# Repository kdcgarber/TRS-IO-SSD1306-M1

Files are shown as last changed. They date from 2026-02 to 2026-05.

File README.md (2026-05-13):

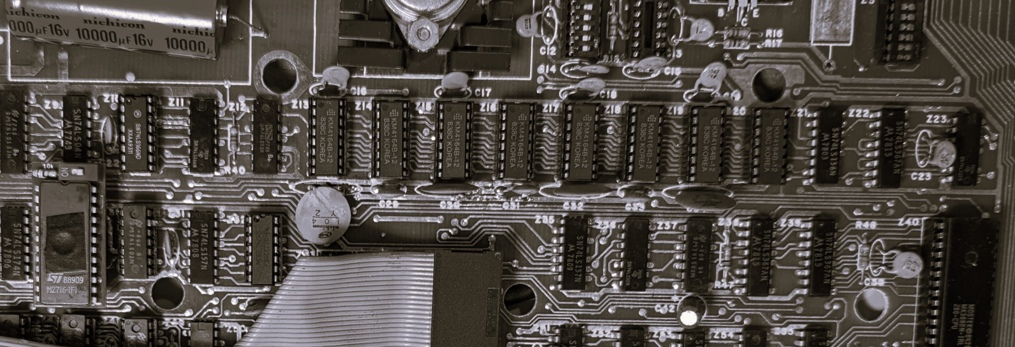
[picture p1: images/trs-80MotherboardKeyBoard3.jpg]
TRS-IO-SSD1306-M1 Header


# TRS-IO with a SSD1306 LCD display for my Model 1
<br>

These are my notes for the build of this version of my TRS-IO<br>
This repo is, like my other repo, based on a snapshot of https://github.com/apuder/TRS-IO commit f2acde6.<br>
That original repo is an amazing piece of hardware/software that provides new feature to my retro TRS-80 model 1<br>
Thanks for making that project hardware design and code avialable for others like me to use on our retro machines.

I’ve built several TRS-IO boards (the earlier versions are on my other GitHub repo), and I’ve now rebuilt them using this updated design.<br>

One challenge I ran into was keeping track of the IP address for each my TRS-IO's.<br>
So, when multiple TRS-IO units are powered on at the same time, it becomes difficult to know which device you’re actually connected to.<br>

To solve that —and mostly just for fun and to learn more— I extended the original design to include a small status display.<br>
This makes it easy to see the assigned IP address and other useful information directly from the TRS-IO itself.<br>

Because this codebase has diverged from the original TRS-IO backported source, I can no longer pull an upstream updates if there are any.<br>
If the original repository is updated in the future, those changes won’t be reflected here unless manually merged.<br>
That said, most current development in this space appears to be shifting toward TRS-IO++, so upstream changes may be minimal going forward.<br>

These notes document the steps I took to configure this new hardware design with my modified software.<br>
They are just notes. They’re primarily for my own reference, but they may also be helpful to others following a similar path.<br>

The new, smaller PCB files that include the display are available in this repo.<br>

The only real difference for the hardware of my board is the part layout <br>
and removing the LED and its resistors to be replaced with a SSD1306 display. <br>
Any TRS-IO could be changed to replace the LED, it just has no mount to hold the display in place, though one can be created. <br>

<table>
  <tr>
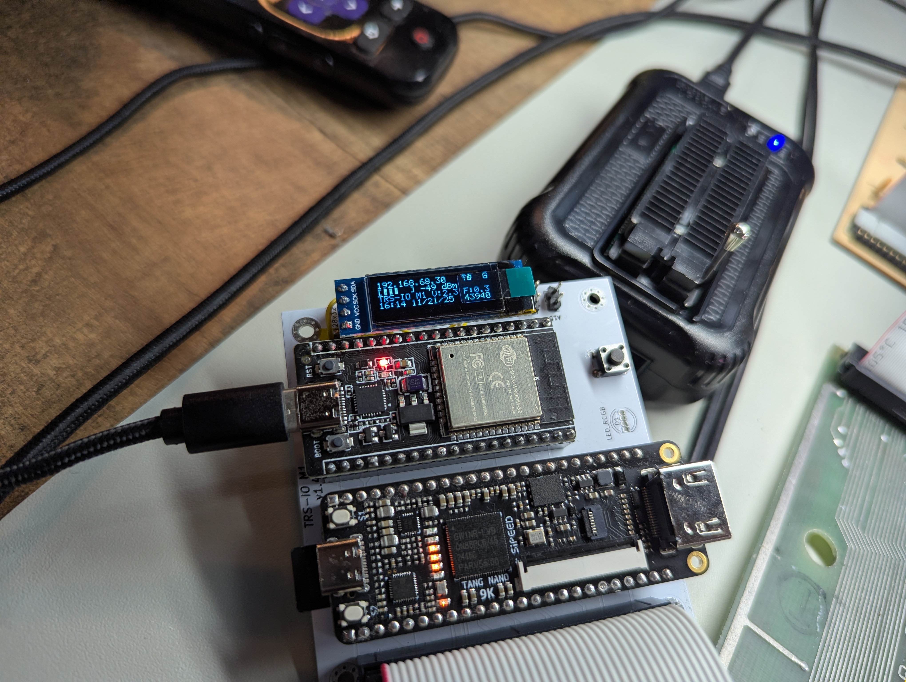
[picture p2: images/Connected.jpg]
	<td></td>
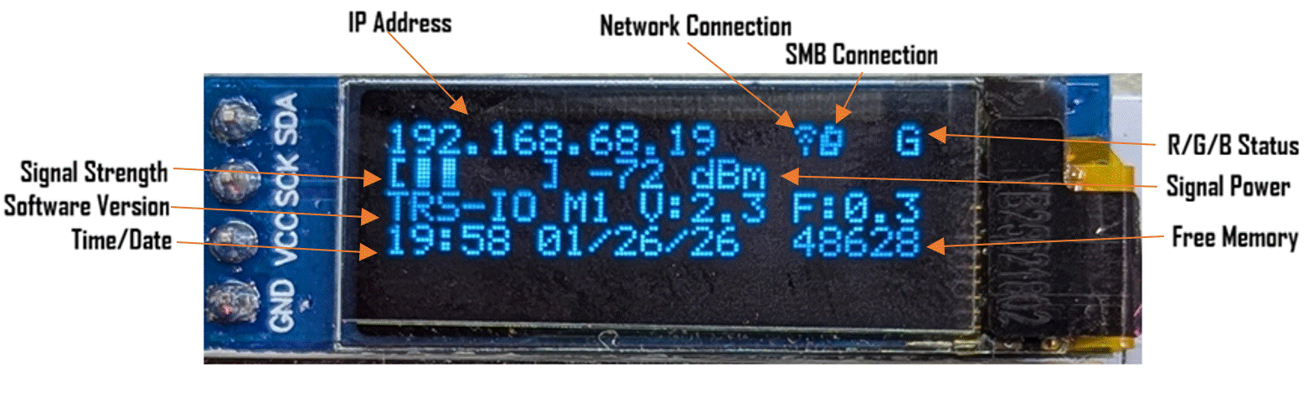
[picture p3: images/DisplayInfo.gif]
	<td></td>
  </tr>
</table>

<bre>

## 📂 Content in repository

	.
	├── DebugNotes.txt                       - Notes to setup my PC to view output from the ESP-WROOM-32 usb port
	├── SDcardM1auto.zip                     - SD card files for the SMB share
	├── 3d                                   - STL files to 3D print a case for the new TRS-IO-SSD1306
	├── buildFiles                           - FPGA file
	├── doc                                  - Doc from the original site
	├── examples                             - Code samples form the Orignal Site
	├── images                               - Images for the github pages
	├── kicad-SSD1306                        - Contains the kicad data for the project PCB
	├── src                                  - This is the altered code for the ESP-WROOM-32
	└── src/esp/ESP-WROOOM-32-Deployment     - Compiled Binary ESP files ready for deployment

<br>

## The hardware build and BOM

All of the files for the PCB are in the kicad-SSD1306 directory.<br>
I sent the files to PCBWay to have them created.<br>
Since you pay per square millimeter of board, by placing all the surface mount components on the back sidek, I saved money on the board cost.<br>
In my final builds I opted to mount the FPGA, ESP32, and display directly to the board to decrease the thickness of the board.<br>
I've done both ways, but in the end, since these are dedicated to this, I went with directly soldering them with no sockets.<br>

<table>
  <tr>
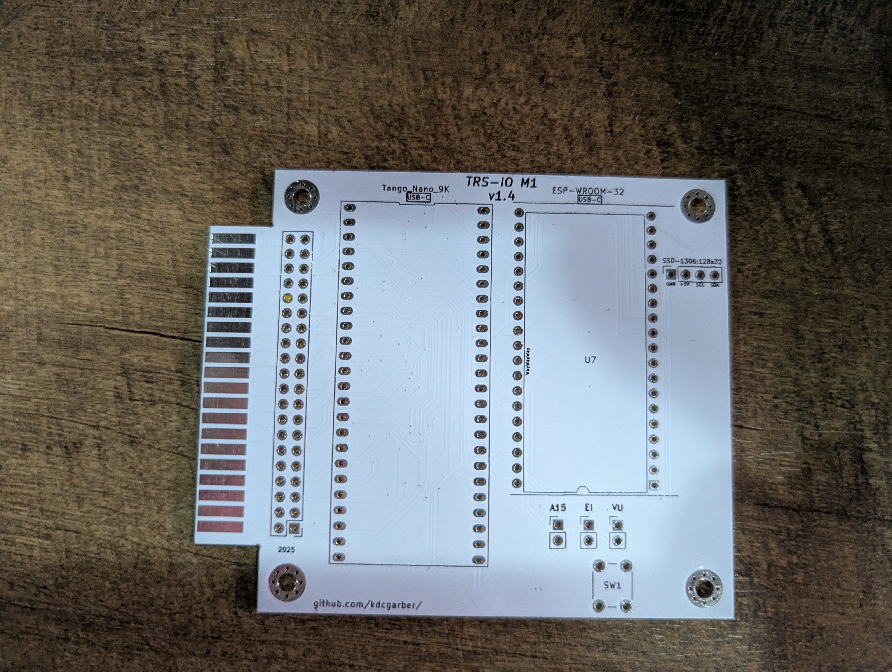
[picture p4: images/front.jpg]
    <td></td>
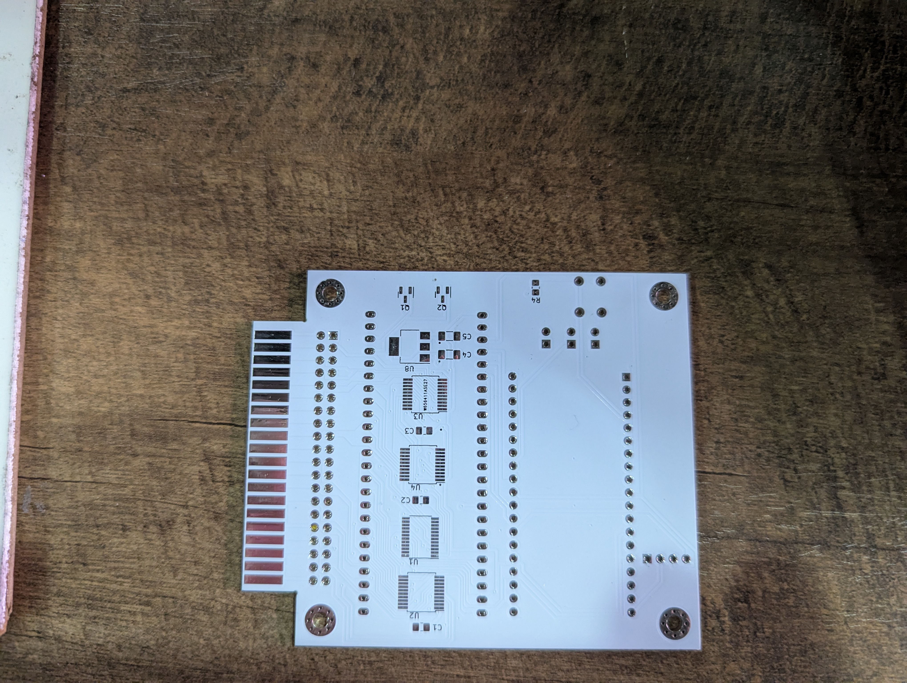
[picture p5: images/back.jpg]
    <td></td>
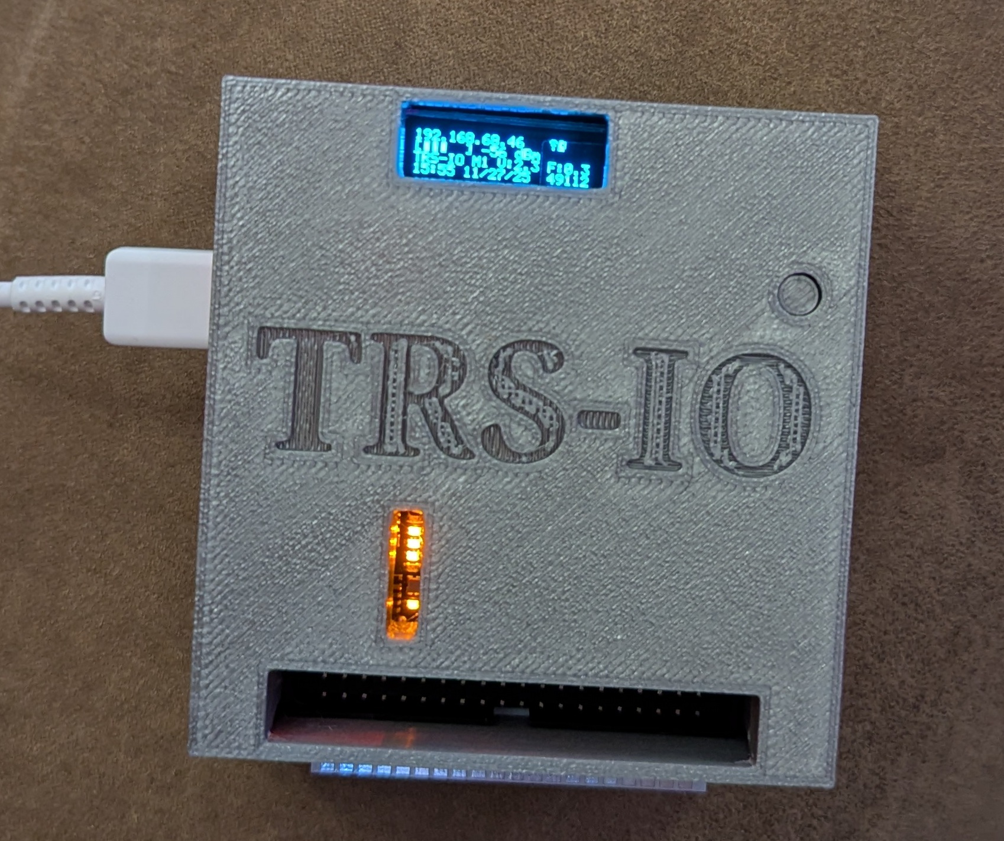
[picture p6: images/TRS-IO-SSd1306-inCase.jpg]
    <td></td>
  </tr>
  <tr>
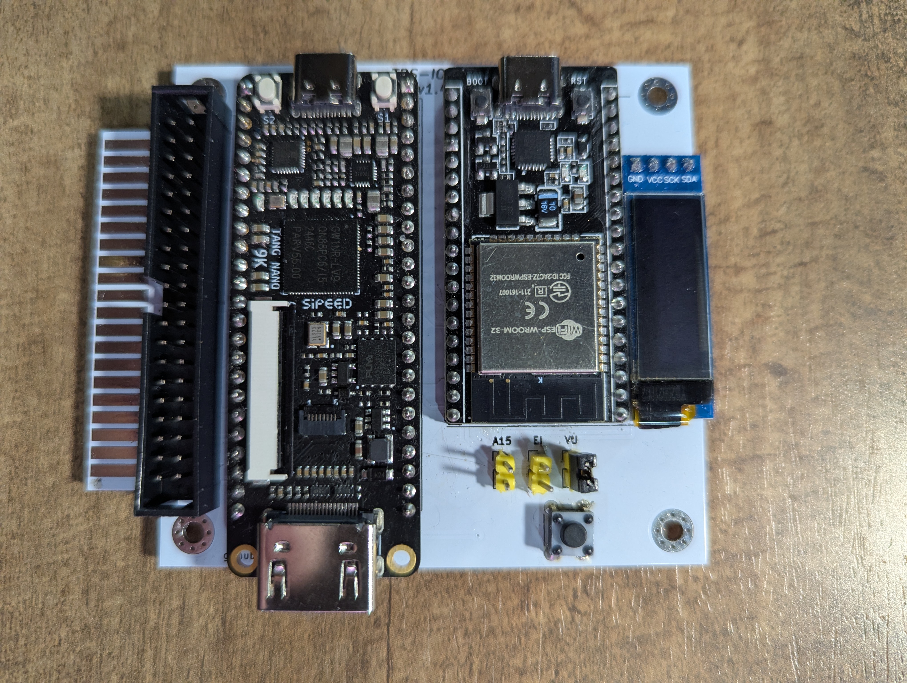
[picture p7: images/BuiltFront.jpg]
    <td></td>
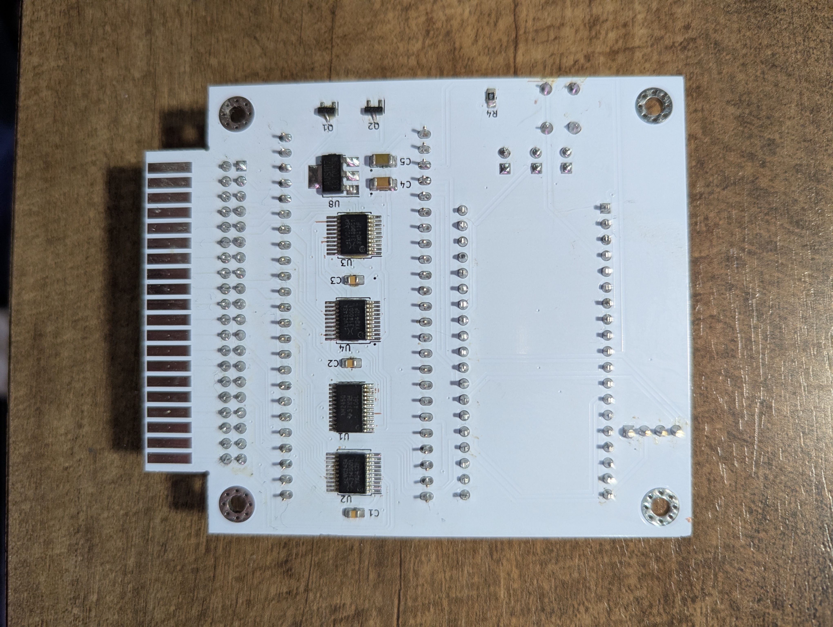
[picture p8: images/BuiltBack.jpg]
    <td></td>
  </tr>
</table>

<br>
The BOM shows the parts needed and their layout and placement.<br>

<a href="https://kdcgarber.github.io/githubPages-htmlfiles/TRS-IO-SSD1306%20bom/ibom.html" target="_blank">Parts list.</a>
<br>

## There are two paths to get the code deployed to your ESP-WROOM-32.

1 Build the files from source and deploy.<br>
2 Just use the pre-built files to flash your ESP.<br>

<br>
<br>

## Option 1 - The Software build for the ESP-WROOM-32

These notes for the code build are based on the original notes of my TRS-IO build.<br>
The code in this repo already has my code changes in it, so no to alter any code by hand.<br>
I built this for my enjoyment and to learn and have fun.<br>
These changes may not be the best code they could be, but if anyone wants to use it, they can.<br>

I used the ESP-WROOM-32 esp controller (no PSRAM) - https://www.amazon.com/dp/B0B764963C<br>
And I used the Tang Nano 9K FPGA - https://www.aliexpress.us/item/3256804089255675.html<br>

I did this code build on Ubuntu 24.04, as a non-root account<br>

### Prep - installing required components<br>
&nbsp;&nbsp;&nbsp;&nbsp;sudo apt upgrade<br>
### Packages for Espressif<br>
&nbsp;&nbsp;&nbsp;&nbsp;sudo apt-get install git wget flex bison gperf python3 python3-pip python3-setuptools cmake ninja-build ccache libffi-dev libssl-dev dfu-util libusb-1.0-0 python3-virtualenv<br>
###  Packages for TRS-IO<br>
&nbsp;&nbsp;&nbsp;&nbsp;sudo apt-get install z80asm sdcc sdcc-libraries<br>
###  Some fixes for linking libraries that are needed by TRS-IO<br>
&nbsp;&nbsp;&nbsp;&nbsp;sudo mkdir -p /lib/z80/<br>
&nbsp;&nbsp;&nbsp;&nbsp;sudo ln -s /usr/share/sdcc/lib/z80/z80.lib /lib/z80/z80.lib<br>
###  Python3 as default:<br>
&nbsp;&nbsp;&nbsp;&nbsp;sudo apt-get install python3 python3-pip python3-setuptools<br>
&nbsp;&nbsp;&nbsp;&nbsp;sudo ln -s /usr/bin/python3 /usr/bin/python<br>
<br>

###  Install ESP-IDF<br>
cd ~/<br>
mkdir esp<br>
cd esp<br>
git clone -b v4.4.7 --recurse-submodules https://github.com/espressif/esp-idf.git<br>
cd ~/esp/esp-idf<br>
./install.sh esp32<br>

### clone this repo
cd ~/esp<br>
git clone --recurse-submodules https://github.com/kdcgarber/TRS-IO-SSD1306-M1.git<br>

### TRS-IO stuff<br>
.  ~/esp/esp-idf/export.sh<br>

## Compile and Flash the ESP<br>
cd ~/esp/TRS-IO-SSD1306-M1/src/esp<br>
idf.py fullclean<br>
make BOARD=trs-io-m1-v14 build<br>

The build will show many warnings, but if it completes with no errors, the rest should be good.<br>
At the bottom of its output, it lists the command to run. The port needs to be changed to match the correct port.<br>

Sometimes while doing the flash, it fails. If it does, just try it again and it will load.<br><br>
~/esp/esp-idf/components/esptool_py/esptool/esptool.py -p /dev/ttyUSB0  -b 460800 --before default_reset --after hard_reset --chip esp32  write_flash --flash_mode dio --flash_size detect --flash_freq 40m 0x1000 build/bootloader/bootloader.bin 0x8000 build/partition_table/partition-table.bin 0x10000 build/trs-io.bin 0x190000 build/html.bin<br>

<br><br><br>

## 💾 Option 2 - Just use the pre-built bin files
<br>
This path is to flash the ESP-WROOM-32 from the provided files without a full code rebuild. <br>
The code does not need to be recompiled unless you are making changes or just want to.
This directory contains 4 files that are the files needed for the ESP: src/esp/ESP-WROOOM-32-Deployment<br>
<br>
• bootloader.bin<br>
• html.bin<br>
• partition-table.bin<br>
• trs-io.bin<br>
<br>

To use these files you'll need to to install ESPTOOL and then deploy the code.<br>
I did my file flash from the files via a windows 11 PC.<br>

From a windows command shell (CMD)<br>
### Check that Python and PIP are installed and install if they are not found. 
python --version<br>
&nbsp;&nbsp;Python 3.12.10<br>

pip --version <br>
&nbsp;&nbsp;pip 25.3 from C:\Users\toddr\AppData\Local\Packages\PythonSoftwareFoundation.Python.3.12_qbz5n2kfra8p0\LocalCache\local-packages\Python312\site-packages\pip (python 3.12)<br>

### This installs the ESPTOOL
pip install esptool<br>

### Add a shortcut to get to the path to use the ESPTOOL
doskey esptool="C:\Users\toddr\AppData\Local\Packages\PythonSoftwareFoundation.Python.3.12_qbz5n2kfra8p0\LocalCache\local-packages\Python312\Scripts\esptool.exe" $* <br>

ESPTOOL should now work<br>

Just enter "esptool", it should give the default help windows message<br>
Plug your ESP-WROOM-32 in via the usb port to your windows 11 pc.<br>

### Now to find the COM port
With the esp plugged into the laptop in windows 11, "mode" will show the COM it's connected to.<br>
The COM will need to be used on the flash command<br>

mode<br>

Status for device COM5:<br>
Baud:            115200<br>
Parity:          None<br>
Data Bits:       8<br>
Stop Bits:       1<br>
Timeout:         OFF<br>
XON/XOFF:        OFF<br>
CTS handshaking: OFF<br>
DSR handshaking: OFF<br>
DSR sensitivity: OFF<br>
DTR circuit:     OFF<br>
RTS circuit:     OFF<br>
<br>

### Move to your code repo and move to the src/esp/ directory. <br>
cd "C:\Users\toddr\OneDrive\Shared\Todd\GitHub\trsnic-ssd1306\src\esp"<br>

There will be 4 bin files in the directory ESP-WROOOM-32-Deployment which will be flashed to the ESP. <br>
 ### Run this command
(Replace COM5 with your actual COM port number if necessary.) <br>

esptool --chip esp32 --port COM5 --baud 460800 write-flash --flash-mode dio --flash-size detect --flash-freq 40m -z 0x1000 ESP-WROOOM-32-Deployment\bootloader.bin 0x8000 ESP-WROOOM-32-Deployment\partition-table.bin 0x10000 ESP-WROOOM-32-Deployment\trs-io.bin 0x190000 ESP-WROOOM-32-Deployment\html.bin <br>

This should flash the ESP and it will now be ready to use.<br>

# Flash the FPGA

### Install openFPGALoader

apt install \\<br>
  git \\<br>
  gzip \\<br>
  libftdi1-2 \\<br>
  libftdi1-dev \\<br>
  libhidapi-hidraw0 \\<br>
  libhidapi-dev \\<br>
  libudev-dev \\<br>
  zlib1g-dev \\<br>
  cmake \\<br>
  pkg-config \\<br>
  make \\<br>
  g++

git clone https://github.com/trabucayre/openFPGALoader<br>
cd openFPGALoader<br>
mkdir build<br>
cd build<br>
cmake .. <br>
cmake --build .<br>
make install<br>

### The FPGA file is TRS-IO.fs<br>

cd  ~/esp/buildFiles<br>
openFPGALoader -b tangnano9k -f TRS-IO.fs

	EXAMPLE:
	root@thebox:/home/kdcgarber/esp/buildFiles# openFPGALoader -b tangnano9k -f TRS-IO.fs

	empty
	write to flash
	Jtag frequency : requested 6.00MHz   -> real 6.00MHz
	Parse file Parse TRS-IO.fs:
	Done
	DONE
	Jtag frequency : requested 2.50MHz   -> real 2.00MHz
	Erase SRAM DONE
	Erase FLASH DONE
	Erasing FLASH: [==================================================] 100.00%
	Done
	write Flash: [==================================================] 100.00%
	Done
	CRC check: Success

<br>

* There is also a newer version of the TRS-IO.fs that I now use. It provides higher resolution glyphs that can be used instead of the original TRS-IO.fs file. It is called TRS-IO-v1_4-HiRes.fs and can be flashed to replace the TRS-IO.fs I used originally.  
openFPGALoader -b tangnano9k -f TRS-IO-v1_4-HiRes.fs

## All done with the Install

After the install is complete, follow the notes on the TRS-IO site to bring up the trs-io.local access point<br> 
and start the configuration.<br>
The site also has the ROM boot loader for the FreHD to go on the SD card<br>
or the SMB (windows share or for me SAMBA share on my Linux server).<br>

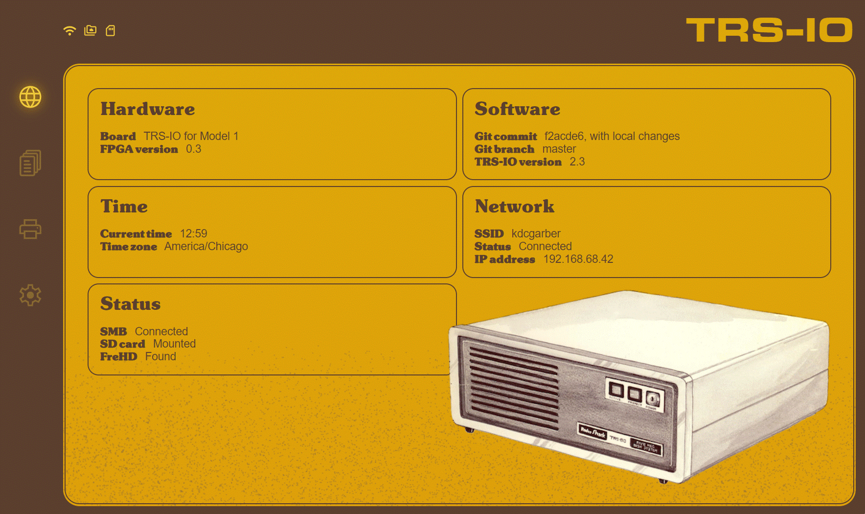
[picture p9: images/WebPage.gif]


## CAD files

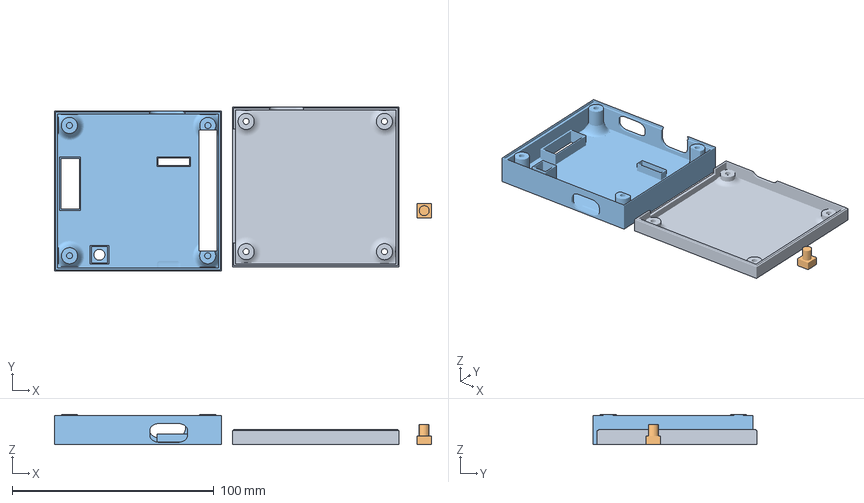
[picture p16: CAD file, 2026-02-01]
kicad-SSD1306/TRS-IO-M1-v1.4-TRG-SSD1306-v6/Case/TRS-IO-M1-v1.4-TRG-SSD1306-v6-FullCase.3mf
186.8 x 81.4 x 15.0 mm
TRS-IO-M1-v1.4-TRG-SSD1306-v6-bottom.stl
TRS-IO-M1-v1.4-TRG-SSD1306-v6-button.stl
TRS-IO-M1-v1.4-TRG-SSD1306-v6-Top.stl

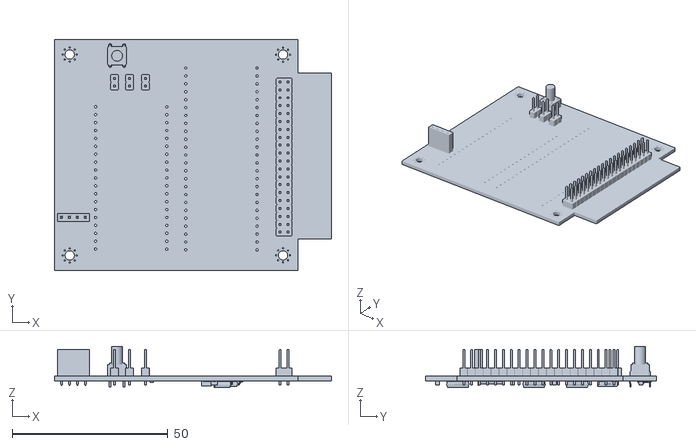
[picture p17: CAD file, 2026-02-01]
3d/TRS-IO Case SSD1306-boardforfun.stl
89.0 x 74.2 x 13.3

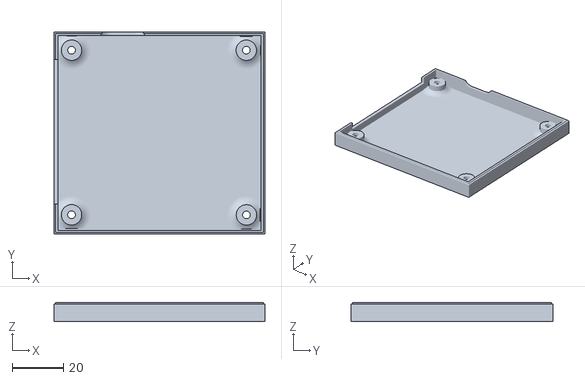
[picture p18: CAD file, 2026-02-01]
kicad-SSD1306/TRS-IO-M1-v1.4-TRG-SSD1306-v6/Case/TRS-IO-M1-v1.4-TRG-SSD1306-v6-bottom.stl
82.7 x 79.3 x 7.50

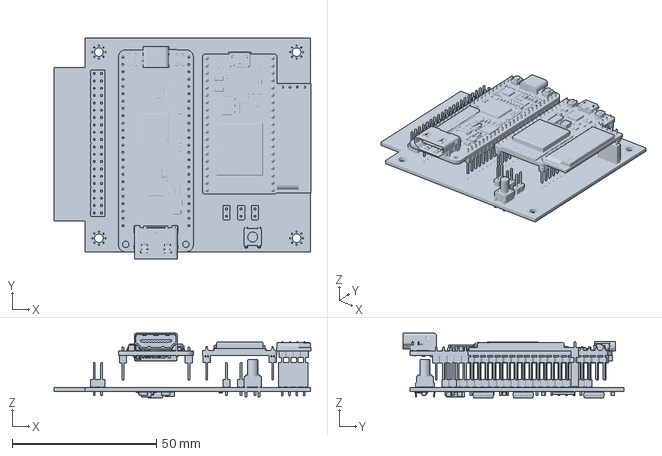
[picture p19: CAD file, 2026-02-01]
kicad-SSD1306/TRS-IO-M1-v1.4-TRG-SSD1306-v6/TRS-IO-M1-v1.4-TRG-SSD1306-v6.3mf
89.1 x 76.5 x 22.5 mm

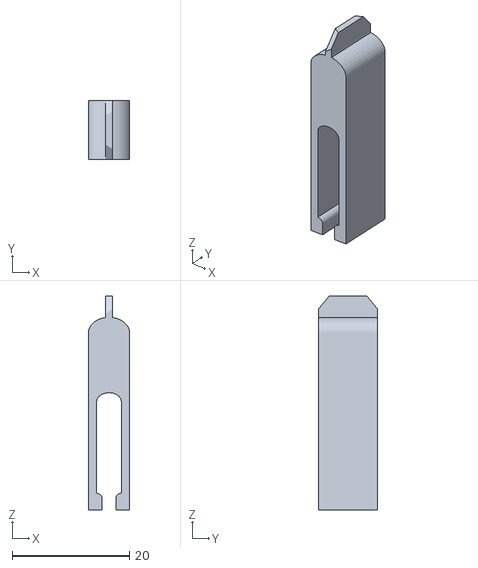
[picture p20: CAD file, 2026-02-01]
3d/Micro_SD_Card_Tool.stl
7.00 x 10.00 x 36.5

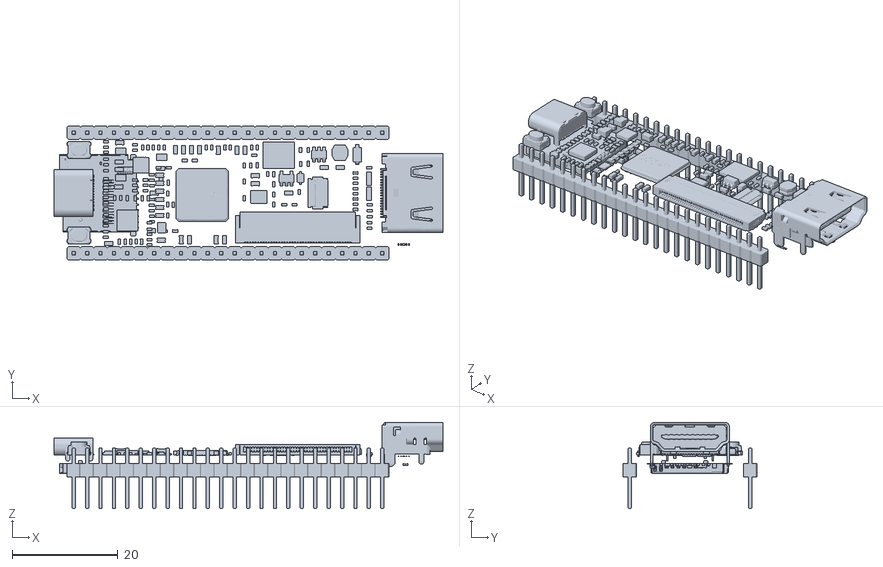
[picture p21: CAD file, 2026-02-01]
kicad-SSD1306/TRS-IO-M1-v1.4-TRG-SSD1306-v6/Tang_Nano_9K_3672.stl
73.6 x 25.4 x 16.4

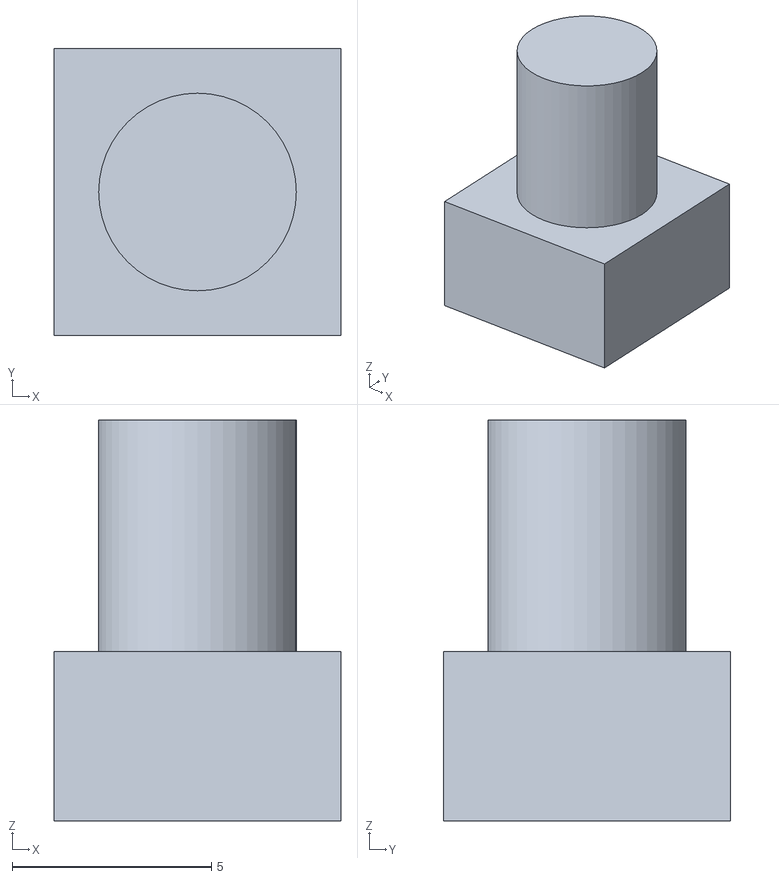
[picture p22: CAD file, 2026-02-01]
3d/TRS-IO Case SSD1306-button.stl
7.20 x 7.20 x 10.1

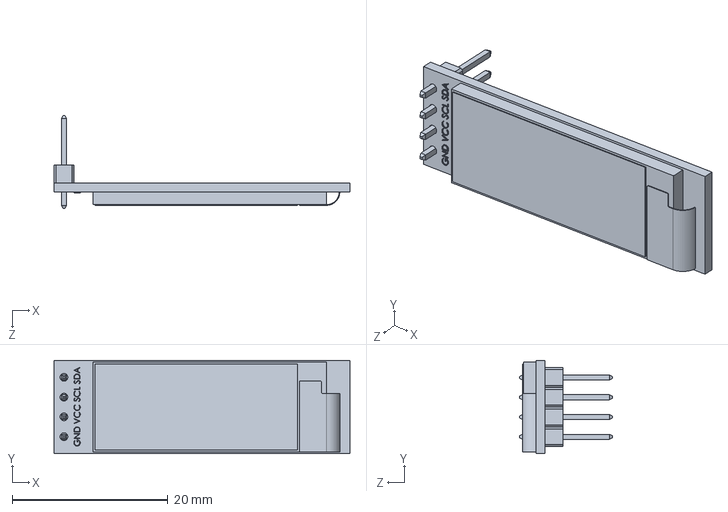
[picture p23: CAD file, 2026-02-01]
kicad-SSD1306/TRS-IO-M1-v1.4-TRG-SSD1306-v6/128x32-OLED.STEP
38.0 x 12.0 x 11.9 mm

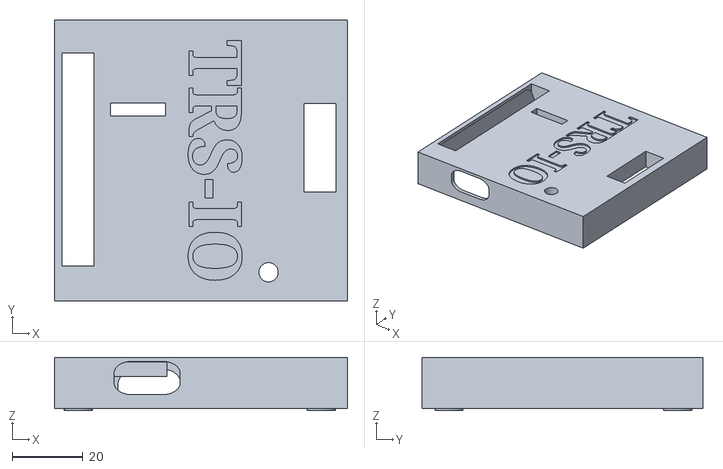
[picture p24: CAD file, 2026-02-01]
kicad-SSD1306/TRS-IO-M1-v1.4-TRG-SSD1306-v6/Case/TRS-IO-M1-v1.4-TRG-SSD1306-v6-Top.stl
82.7 x 79.3 x 15.0

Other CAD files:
kicad-SSD1306/TRS-IO-M1-v1.4-TRG-SSD1306-v6/Case/TRS-IO-M1-v1.4-TRG-SSD1306-v6-button.stl
3d/TRS-IO Case SSD1306-Bottom.stl
kicad-SSD1306/TRS-IO-M1-v1.4-TRG-SSD1306-v6/TRS-IO-M1-v1.4-TRG-SSD1306-v6-ReducefileSize-1.stl
3d/TRS-IO Case SSD1306-Top.stl
kicad-SSD1306/TRS-IO-M1-v1.4-TRG-SSD1306-v6/TRS-IO-M1-v1.4-TRG-SSD1306-v6.stl

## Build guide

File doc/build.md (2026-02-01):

#### TRS-IO - Circuit Board Bill of Materials

|Qty|Ref|Digikey Part#|Manuf Part #|Description|
|:---|:---|:---|:---|:---|
|1|U1||ESP32 MODULE|Refer to Supported ESP32 Modules
|1|U3|[ATF16V8B-15PU-ND](https://www.digikey.com/product-detail/en/microchip-technology/ATF16V8B-15PU/ATF16V8B-15PU-ND/1118926)|ATF16V8B-15PU|IC PLD 8MC 15NS 20DIP
|2|U2,U4|[296-8503-5-ND](https://www.digikey.com/product-detail/en/texas-instruments/SN74LVC245AN/296-8503-5-ND/377483)|SN74LVC245AN|IC TXRX NON-INVERT 3.6V 20DIP
|3|Q1,Q2,Q3|[2N7000-G-ND](https://www.digikey.com/product-detail/en/microchip-technology/2N7000-G/2N7000-G-ND/4902350)|2N7000-G|MOSFET N-CH 60V 0.2A TO92-3
|1|D1|[1830-1014-ND](https://www.digikey.com/product-detail/en/inolux/HV-5RGB60/1830-1014-ND/7604616)|HV-5RGB60|LED RGB DIFFUSED 5MM T/H
|1|SW1|[450-1650-ND](https://www.digikey.com/product-detail/en/te-connectivity-alcoswitch-switches/1825910-6/450-1650-ND/1632536)|1825910-6|SWITCH TACTILE SPST-NO 0.05A 24V
|1|SW2||1825910-6|SWITCH TACTILE RIGHT-ANGLE SPST-NO 0.05A 24V
|3|U2,U3,U4|[ED3054-5-ND](https://www.digikey.com/product-detail/en/on-shore-technology-inc/ED20DT/ED3054-5-ND/4147598)|ED20DT|CONN IC DIP SOCKET 20POS TIN
|1|J1|[ED10530-ND](https://www.digikey.com/product-detail/en/on-shore-technology-inc/302-S501/ED10530-ND/2794241)|302-S501|CONN HEADER VERT 50POS 2.54MM
|1||[HDR100IMP40F-G-V-TH-ND](https://www.digikey.com/product-detail/en/chip-quik-inc/HDR100IMP40F-G-V-TH/HDR100IMP40F-G-V-TH-ND/5978200)|HDR100IMP40F-G-V-TH|SIL HDR 40POS 0.1 GOLD PCB
|4|C1,C2,C3,C4|[490-8809-ND](https://www.digikey.com/short/pvj15w)|RDER71E104K0P1H03B|CAP CER 0.1UF 25V X7R RADIAL
|3|R1,R2,R3|||100R 0.25W
|1|R4|||4K7 0.25W

#### Supported ESP32 Modules:
The TRS-IO board supports two commonly available ESP32 modules.

* 38 Pin Module commonly branded as NodeMCU or HiLetGo

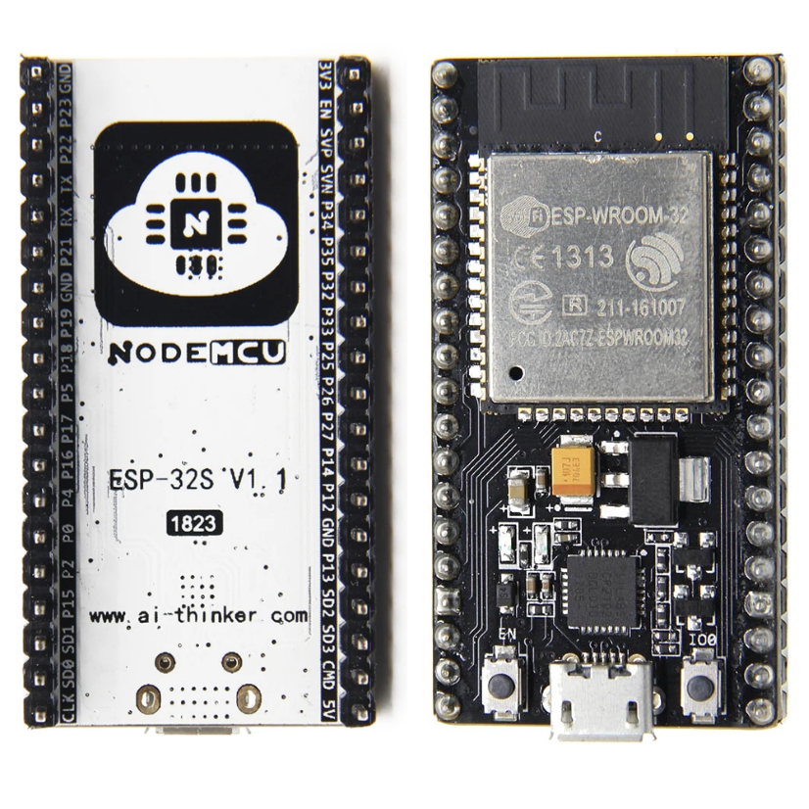
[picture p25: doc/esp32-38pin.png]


* 30 Pin Module commonly branded as DEVKITV1

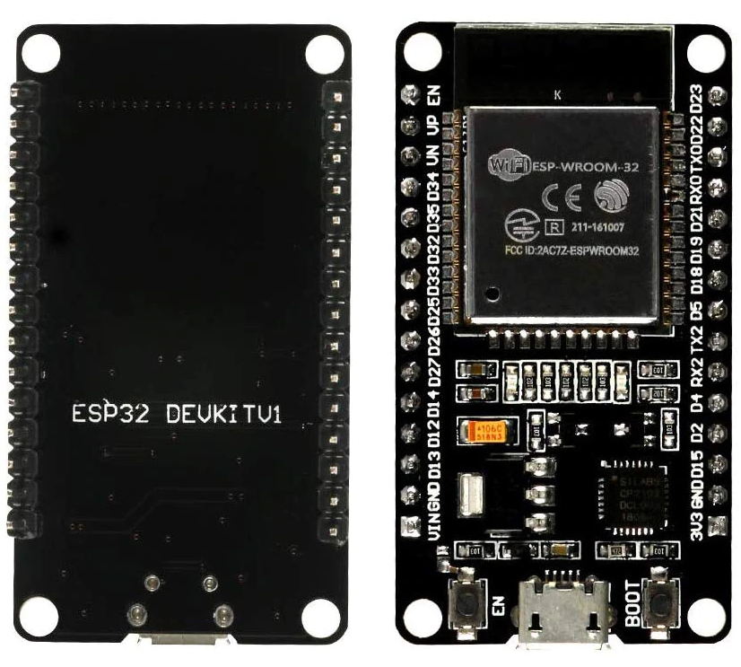
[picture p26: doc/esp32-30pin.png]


The pinout and spacing of the two modules differs.  Unless you plan to test your board with both modules, install 15 pin SIL sockets in 1st and 3rd positons for the 30 Pin Module or 19 pin SIL sockets in the 2nd and 4th positions for the 38 Pin Module.

Correct orientation of the modules is shown below:

* 38 Pin Module commonly branded as NodeMCU or HiLetGo

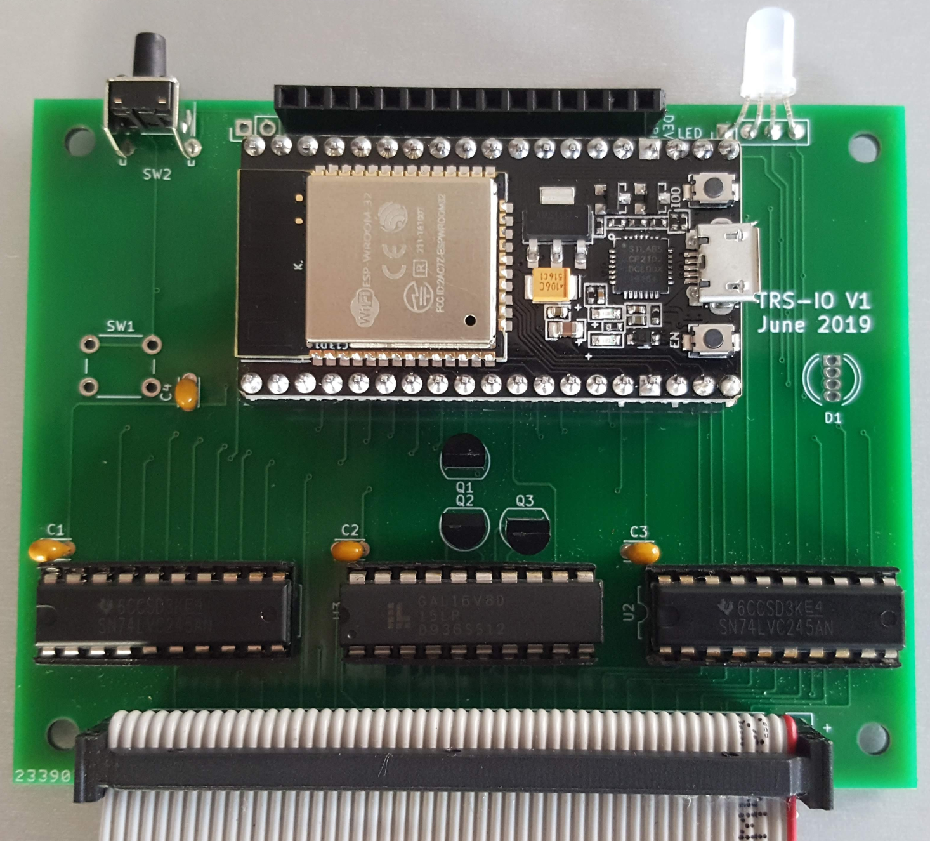
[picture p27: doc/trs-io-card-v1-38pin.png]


* 30 Pin Module commonly branded as DEVKITV1

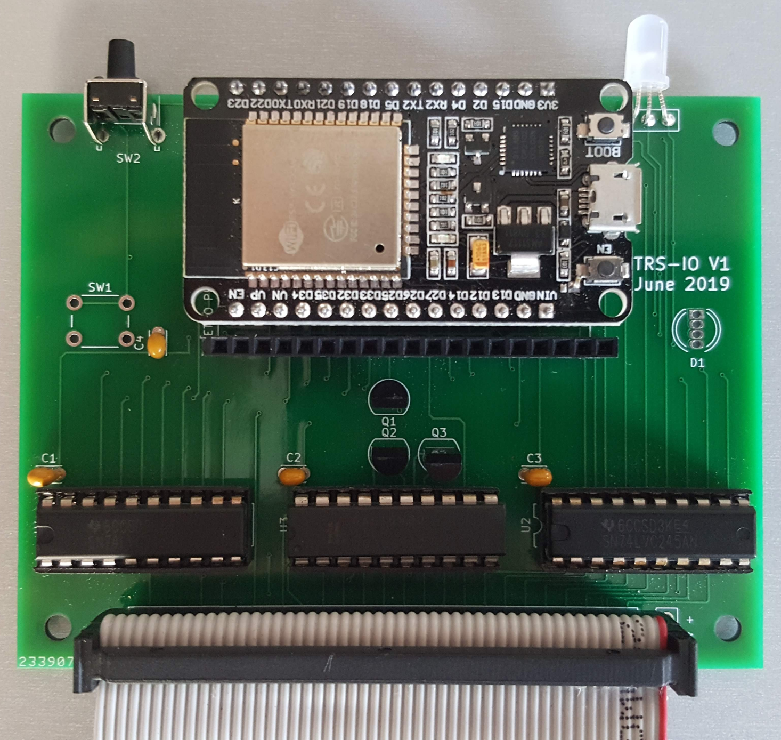
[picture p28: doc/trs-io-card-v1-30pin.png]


#### Notes:
* The switch can be installed in either SW1 or SW2.  SW2 is recommended when assembling the board for installation in a case.
* The LED can be installed in either D1 or J4.  J4 is recommended when assembling the board for installation in a case.  Do not install an LED in both D1 and J4.
* R1,R2 and R3 are current limiting resistors for the LED.  The values are not critical and may require adjustment for some LED.
* The J5 header can be installed and jumpered to disable the internal FreHD emulation when an external FreHD is connected to the expansion connector.  J5 can be omitted if an external FreHD is not used.
* R4 is a pullup for the ESP32 FreHD Inhibit signal. This must always be installed even J5 is not.  Value is not critical.  Anything between 4K7 and 10K will work.
* 5V can be connected to J5 as an alternative to powering ESP32 from USB.  This is recommended when assembling the board for installation in a case.

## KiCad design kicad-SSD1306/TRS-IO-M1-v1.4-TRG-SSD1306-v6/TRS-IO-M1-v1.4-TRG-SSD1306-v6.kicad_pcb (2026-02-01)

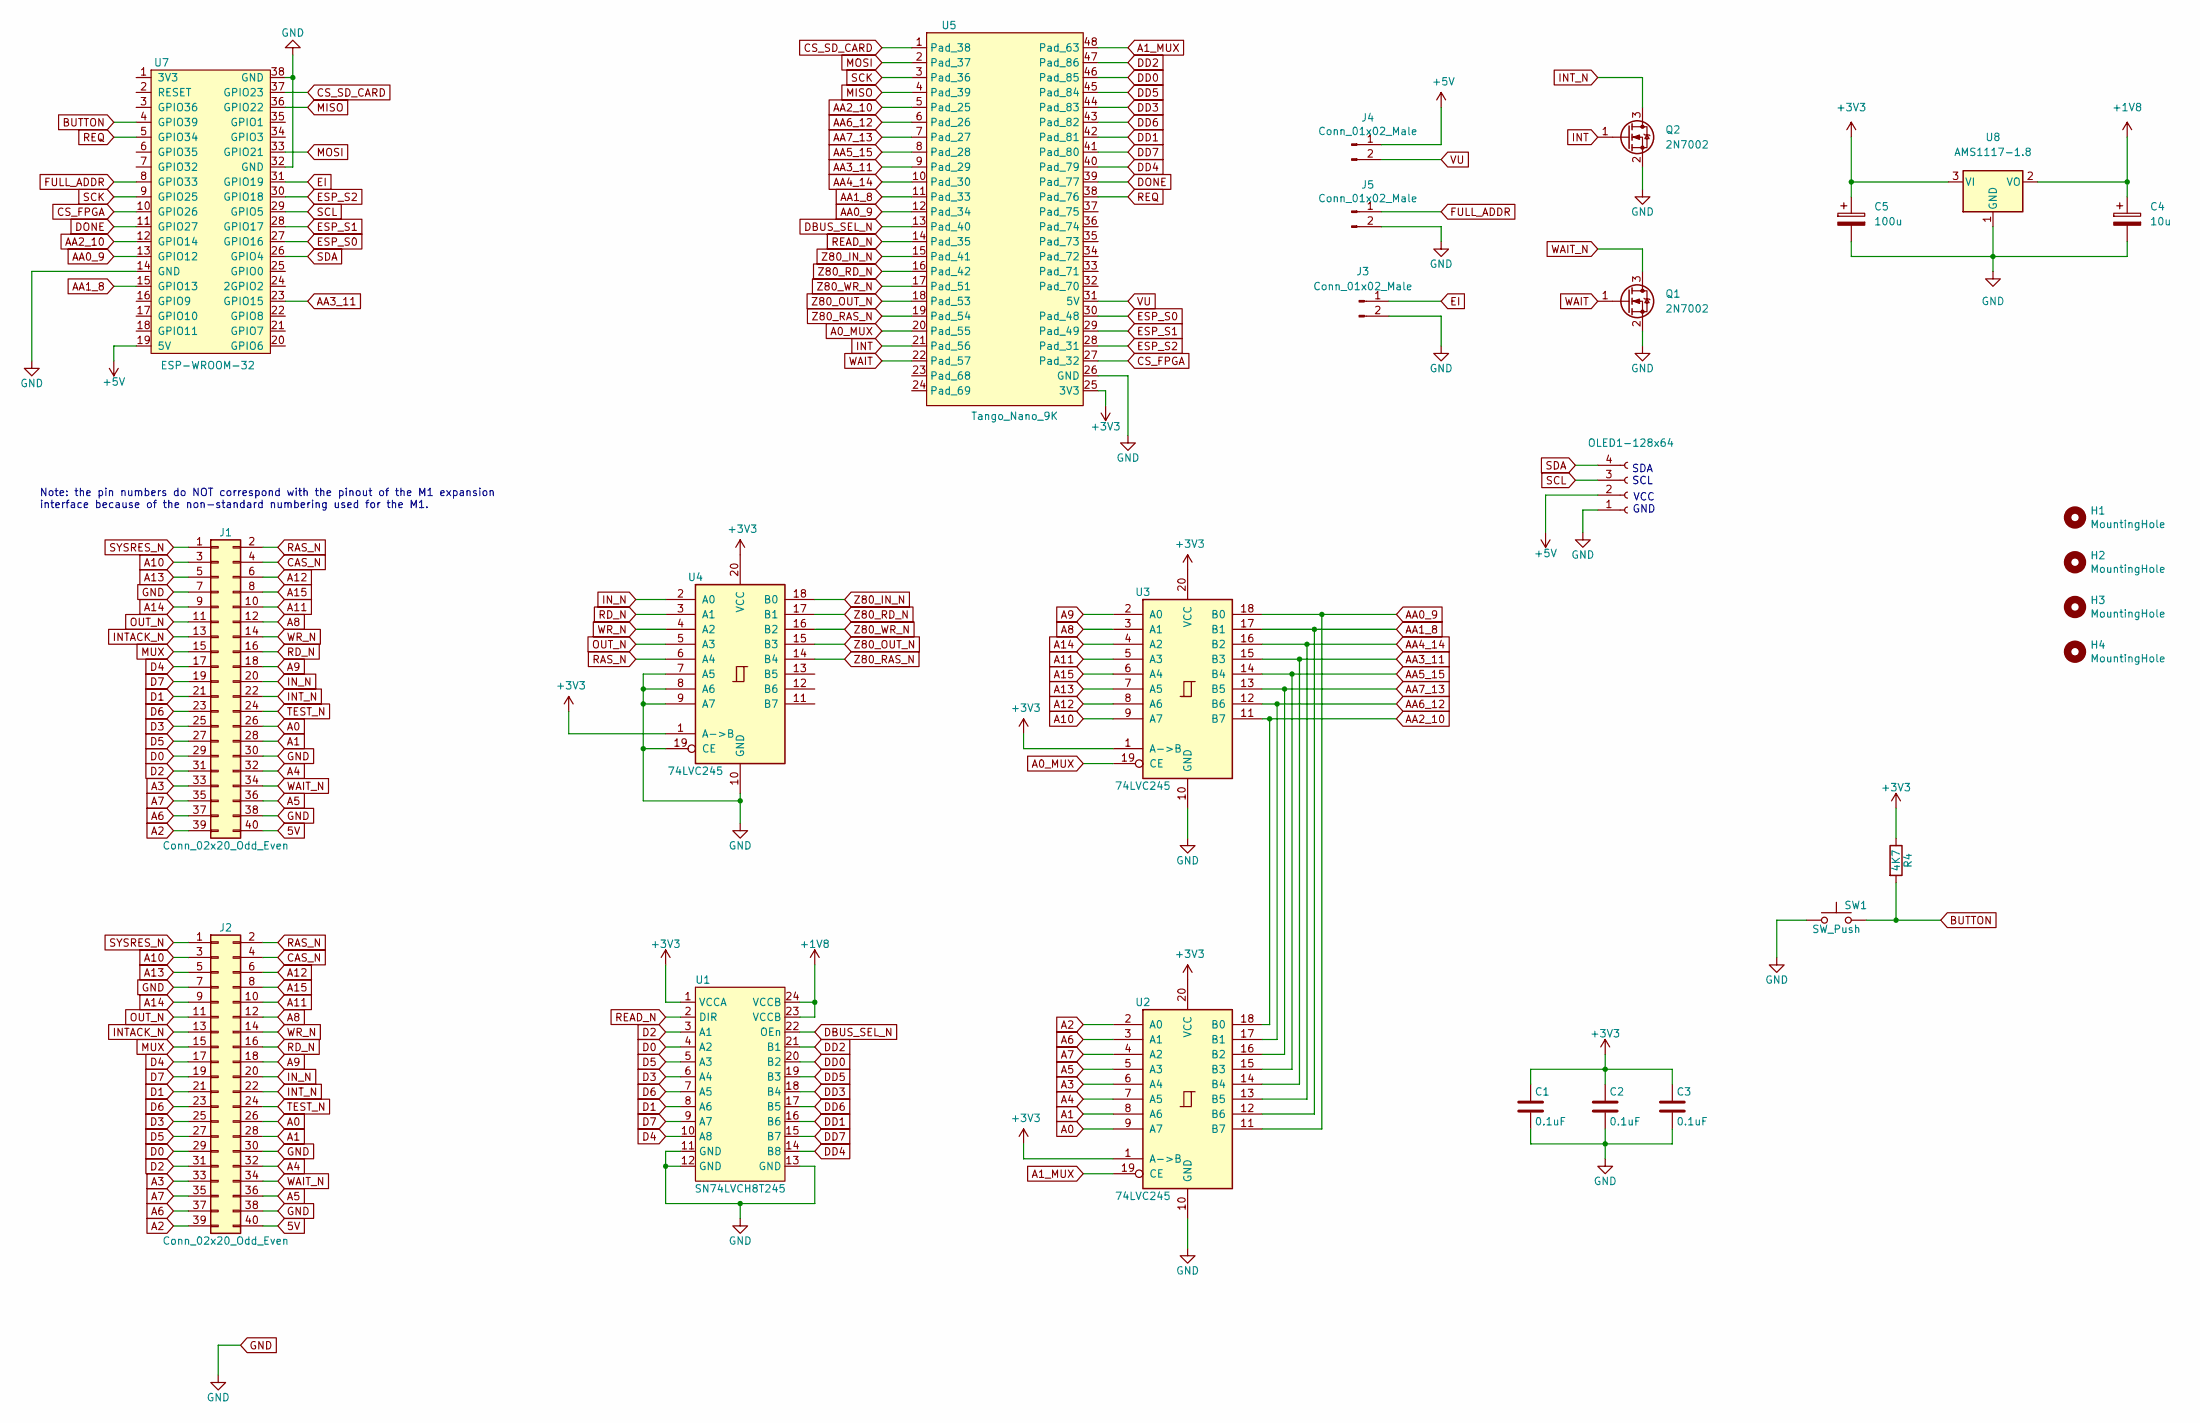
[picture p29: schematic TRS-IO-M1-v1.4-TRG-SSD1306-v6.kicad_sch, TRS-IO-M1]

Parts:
C1, C2, C3: 0.1uF; C_0805_2012Metric_Pad1.18x1.45mm_HandSolder
C4: 10u; C_1206_3216Metric_Pad1.33x1.80mm_HandSolder
C5: 100u; C_1206_3216Metric_Pad1.33x1.80mm_HandSolder
H1, H2, H3, H4: MountingHole; MountingHole_3mm_Pad_Via
J1: Conn_02x20_Odd_Even; PinHeader_2x20_P2.54mm_Vertical
J2: Conn_02x20_Odd_Even; TRSEDGE
J3, J4, J5: Conn_01x02_Male; PinHeader_1x02_P2.54mm_Vertical
OLED1-128x64: Conn_01x04_Socket; PinSocket_1x04_P2.54mm_Vertical
Q1, Q2: 2N7002; SOT-23
R4: 4K7; R_0805_2012Metric_Pad1.20x1.40mm_HandSolder
SW1: SW_Push; SW_PUSH_6mm_H9.5mm
U1: SN74LVCH8T245; TSSOP-24_4.4x7.8mm_P0.65mm
U2, U3, U4: 74LVC245; SSOP-20_5.3x7.2mm_P0.65mm_slim
U5: Tango_Nano_9K; DIP-48_W22.9mm
U7: ESP-WROOM-32; DIP-38_W22.9mm
U8: AMS1117-1.8; SOT-223-3_TabPin2

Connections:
5V: J1.40, J2.40
+1V8: C4.1, U1.23 (VCCB), U1.24 (VCCB), U8.2 (VO)
+3V3: C1.1, C2.1, C3.1, C5.1, R4.1, U1.1 (VCCA), U2.1 (A->B), U2.20 (VCC), U3.1 (A->B), U3.20 (VCC), U4.1 (A->B), U4.20 (VCC), U5.25 (3V3), U8.3 (VI)
+5V: J4.1, OLED1-128x64.2, U7.19 (5V); also elsewhere on the board
A0: J1.26, J2.26, U2.9 (A7)
A0_MUX: U3.19 (CE), U5.20 (Pad_55)
A1: J1.28, J2.28, U2.8 (A6)
A1_MUX: U2.19 (CE), U5.48 (Pad_63)
A2: J1.39, J2.39, U2.2 (A0)
A3: J1.33, J2.33, U2.6 (A4)
A4: J1.32, J2.32, U2.7 (A5)
A5: J1.36, J2.36, U2.5 (A3)
A6: J1.37, J2.37, U2.3 (A1)
A7: J1.35, J2.35, U2.4 (A2)
A8: J1.12, J2.12, U3.3 (A1)
A9: J1.18, J2.18, U3.2 (A0)
A10: J1.3, J2.3, U3.9 (A7)
A11: J1.10, J2.10, U3.5 (A3)
A12: J1.6, J2.6, U3.8 (A6)
A13: J1.5, J2.5, U3.7 (A5)
A14: J1.9, J2.9, U3.4 (A2)
A15: J1.8, J2.8, U3.6 (A4)
AA0_9: U2.11 (B7), U3.18 (B0), U5.12 (Pad_34), U7.13 (GPIO12)
AA1_8: U2.12 (B6), U3.17 (B1), U5.11 (Pad_33), U7.15 (GPIO13)
AA2_10: U2.18 (B0), U3.11 (B7), U5.5 (Pad_25), U7.12 (GPIO14)
AA3_11: U2.14 (B4), U3.15 (B3), U5.9 (Pad_29), U7.23 (GPIO15)
AA4_14: U2.13 (B5), U3.16 (B2), U5.10 (Pad_30)
AA5_15: U2.15 (B3), U3.14 (B4), U5.8 (Pad_28)
AA6_12: U2.17 (B1), U3.12 (B6), U5.6 (Pad_26)
AA7_13: U2.16 (B2), U3.13 (B5), U5.7 (Pad_27)
BUTTON: R4.2, SW1.2, U7.4 (GPIO39)
CAS_N: J1.4, J2.4
CS_FPGA: U5.27 (Pad_32), U7.10 (GPIO26)
CS_SD_CARD: U5.1 (Pad_38), U7.37 (GPIO23)
D0: J1.29, J2.29, U1.4 (A2)
D1: J1.21, J2.21, U1.8 (A6)
D2: J1.31, J2.31, U1.3 (A1)
D3: J1.25, J2.25, U1.6 (A4)
D4: J1.17, J2.17, U1.10 (A8)
D5: J1.27, J2.27, U1.5 (A3)
D6: J1.23, J2.23, U1.7 (A5)
D7: J1.19, J2.19, U1.9 (A7)
DBUS_SEL_N: U1.22 (OEn), U5.13 (Pad_40)
DD0: U1.20 (B2), U5.46 (Pad_85)
DD1: U1.16 (B6), U5.42 (Pad_81)
DD2: U1.21 (B1), U5.47 (Pad_86)
DD3: U1.18 (B4), U5.44 (Pad_83)
DD4: U1.14 (B8), U5.40 (Pad_79)
DD5: U1.19 (B3), U5.45 (Pad_84)
DD6: U1.17 (B5), U5.43 (Pad_82)
DD7: U1.15 (B7), U5.41 (Pad_80)
DONE: U5.39 (Pad_77), U7.11 (GPIO27)
EI: J3.1, U7.31 (GPIO19)
ESP_S0: U5.30 (Pad_48), U7.27 (GPIO16)
ESP_S1: U5.29 (Pad_49), U7.28 (GPIO17)
ESP_S2: U5.28 (Pad_31), U7.30 (GPIO18)
FULL_ADDR: J5.1, U7.8 (GPIO33)
GND: C1.2, C2.2, C3.2, C4.2, C5.2, J1.7, J1.30, J1.38, J2.7, J2.30, J2.38, J3.2, J5.2, OLED1-128x64.1, Q1.2 (S), Q2.2 (S), SW1.1, U1.11 (GND), U1.12 (GND), U1.13 (GND), U2.10 (GND), U3.10 (GND), U4.7 (A5), U4.8 (A6), U4.9 (A7), U4.10 (GND), U4.19 (CE), U5.26 (GND), U7.14 (GND), U7.32 (GND), U7.38 (GND), U8.1 (GND); also elsewhere on the board
INT: Q2.1 (G), U5.21 (Pad_56)
INTACK_N: J1.13, J2.13
INT_N: J1.22, J2.22, Q2.3 (D)
IN_N: J1.20, J2.20, U4.2 (A0)
MISO: U5.4 (Pad_39), U7.36 (GPIO22)
MOSI: U5.2 (Pad_37), U7.33 (GPIO21)
MUX: J1.15, J2.15
OUT_N: J1.11, J2.11, U4.5 (A3)
RAS_N: J1.2, J2.2, U4.6 (A4)
RD_N: J1.16, J2.16, U4.3 (A1)
READ_N: U1.2 (DIR), U5.14 (Pad_35)
REQ: U5.38 (Pad_76), U7.5 (GPIO34)
SCK: U5.3 (Pad_36), U7.9 (GPIO25)
SCL: OLED1-128x64.3, U7.29 (GPIO5); also elsewhere on the board
SDA: OLED1-128x64.4, U7.26 (GPIO4); also elsewhere on the board
SYSRES_N: J1.1, J2.1
TEST_N: J1.24, J2.24
VU: J4.2, U5.31 (5V)
WAIT: Q1.1 (G), U5.22 (Pad_57)
WAIT_N: J1.34, J2.34, Q1.3 (D)
WR_N: J1.14, J2.14, U4.4 (A2)
Z80_IN_N: U4.18 (B0), U5.15 (Pad_41)
Z80_OUT_N: U4.15 (B3), U5.18 (Pad_53)
Z80_RAS_N: U4.14 (B4), U5.19 (Pad_54)
Z80_RD_N: U4.17 (B1), U5.16 (Pad_42)
Z80_WR_N: U4.16 (B2), U5.17 (Pad_51)

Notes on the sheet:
VCC GND
SDA SCL
Note: the pin numbers do NOT correspond with the pinout of the M1 expansion interface because of the non-standard numbering used for the M1.

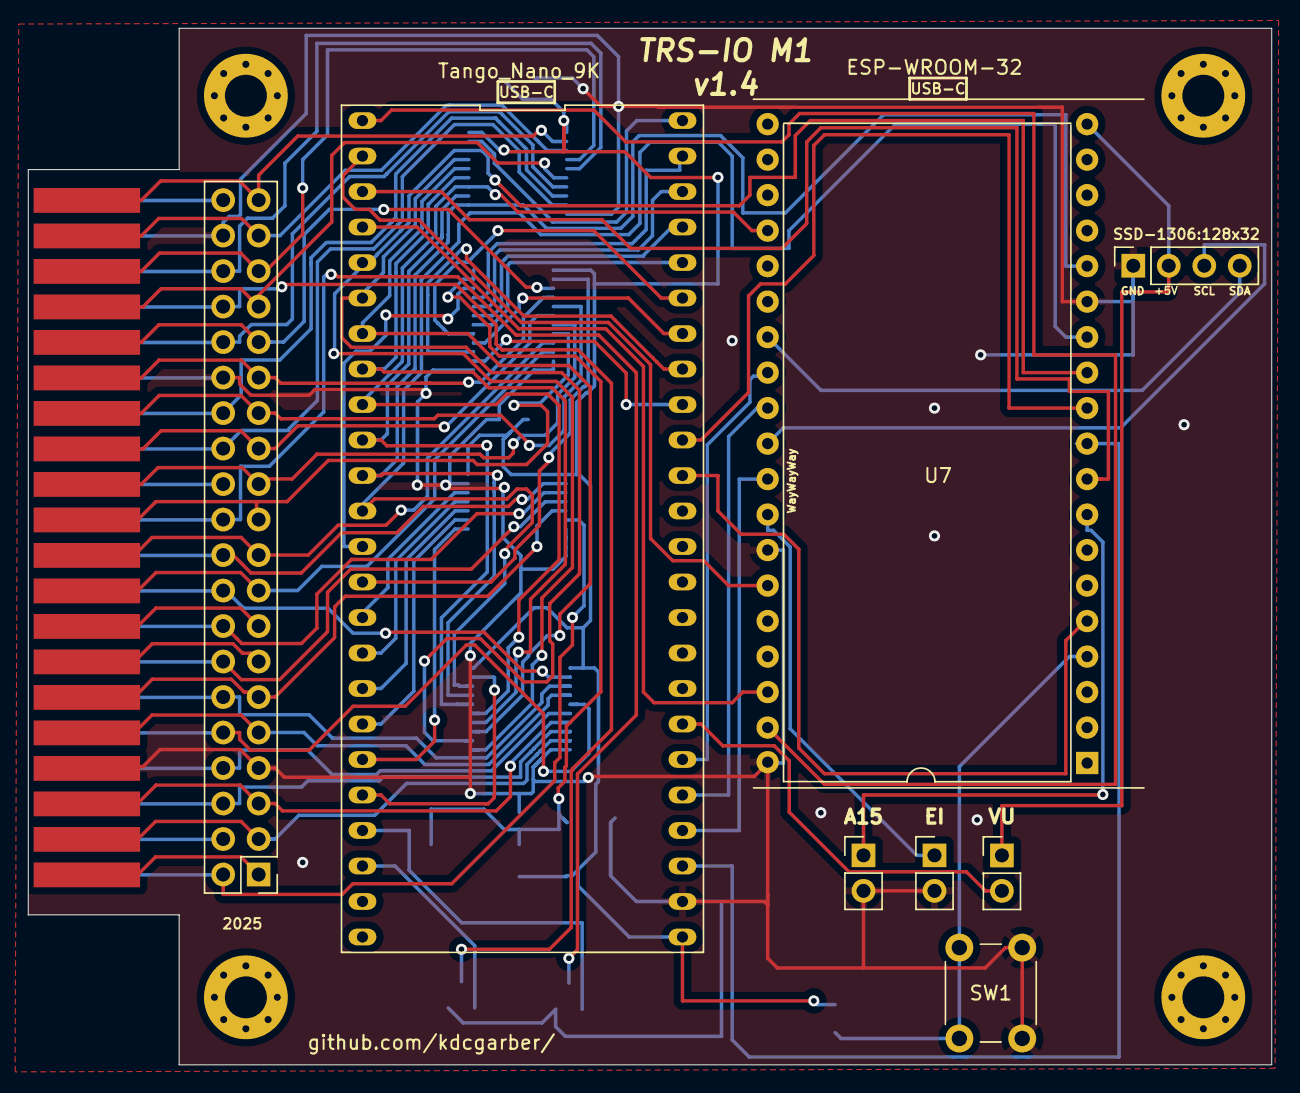
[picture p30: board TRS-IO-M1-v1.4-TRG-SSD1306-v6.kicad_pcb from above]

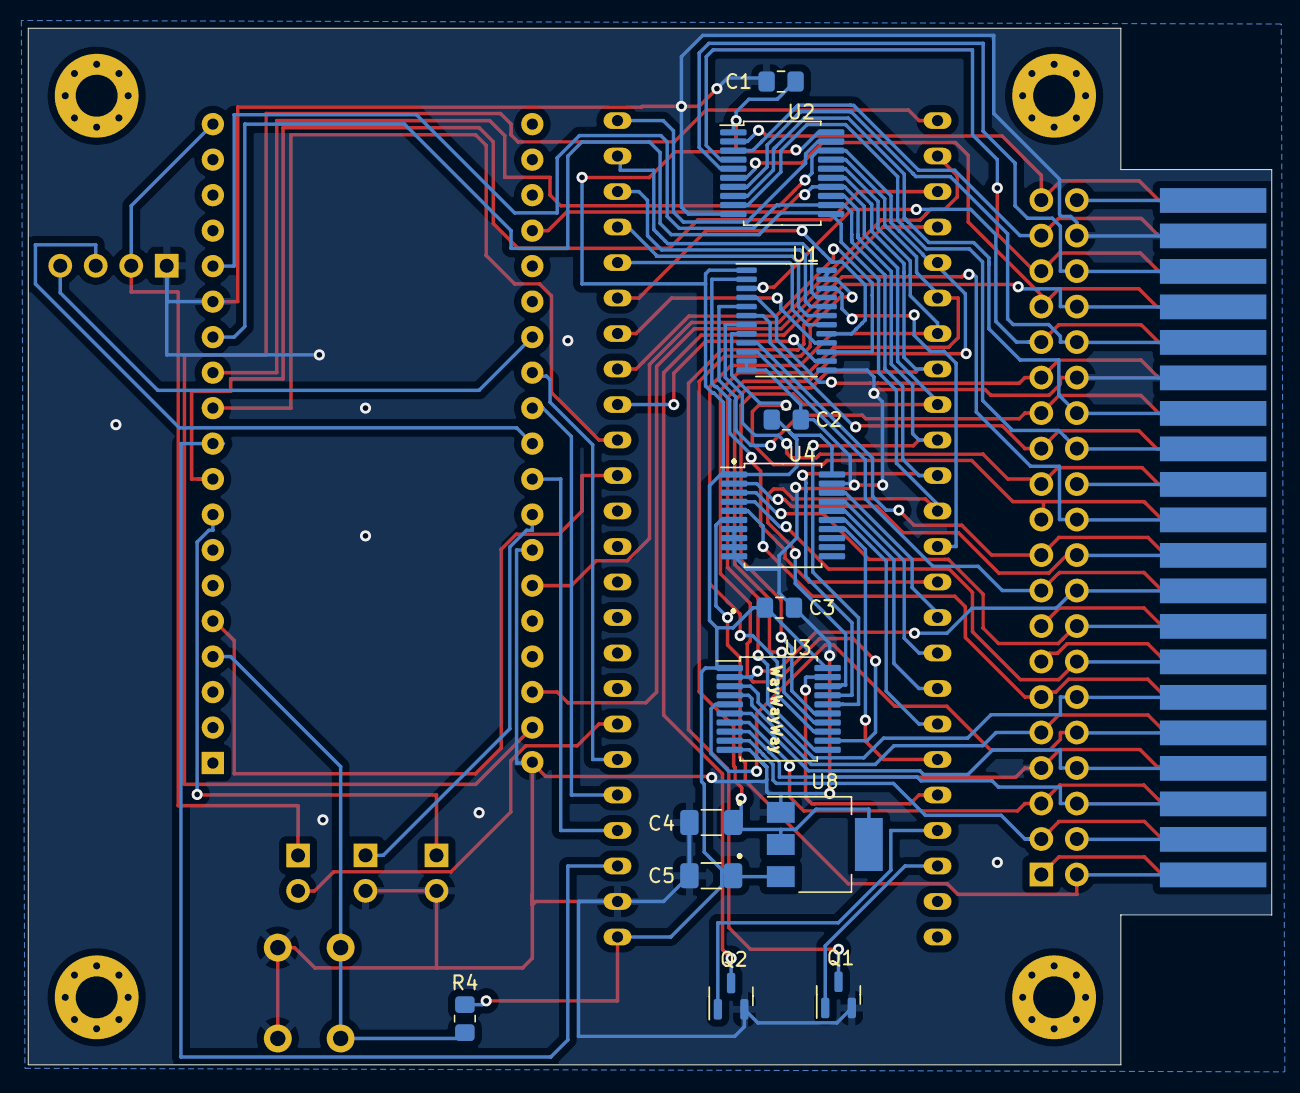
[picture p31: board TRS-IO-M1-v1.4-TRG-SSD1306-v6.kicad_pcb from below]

Board: 2 copper layers, 89.0 x 74.2 mm, 26 parts (13 on the bottom side), 84 nets.

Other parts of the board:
SSD-1306:128x32: Conn_01x04_Socket; PinSocket_1x04_P2.54mm_Vertical

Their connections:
+5V: SSD-1306:128x32.2; also elsewhere on the board
GND: SSD-1306:128x32.1; also elsewhere on the board
SCL: SSD-1306:128x32.3; also elsewhere on the board
SDA: SSD-1306:128x32.4; also elsewhere on the board

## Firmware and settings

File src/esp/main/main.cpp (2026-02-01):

#include "io.h"
#include "led.h"
#include "button.h"
#include "wifi.h"
#include "http.h"
#include "ota.h"
#include "settings.h"
#include "event.h"
#include "esp_event.h"
#include "esp_log.h"
#include "esp_system.h"
#include "esp_spi_flash.h"
#include "esp32/spiram.h"
#include "esp_ota_ops.h"

#include "trs-io.h"
#include "trs-fs.h"
#include "spi.h"
#include "keyb.h"
#include "ptrs.h"
#include "xflash.h"
#include "spiffs.h"

#include "esp_idf_version.h"

#include "ssd1306.h"

#if ESP_IDF_VERSION != ESP_IDF_VERSION_VAL(4, 4, 7)
#error Please use ESP-IDF version 4.4.7
#endif

#define TAG "TRS-IO"

#ifdef CONFIG_TRS_IO_MODEL_1
#define CONFIG "TRS-IO (Model 1)"
#endif
#ifdef CONFIG_TRS_IO_MODEL_3
#define CONFIG "TRS-IO (Model III)"
#endif
#ifdef CONFIG_TRS_IO_PP
#define CONFIG "TRS-IO++"
#endif

extern const char* GIT_REV;
extern const char* GIT_BRANCH;


static void check()
{
#ifdef CONFIG_TRS_IO_PP
  size_t flash_size = spi_flash_get_chip_size() / (1024 * 1024);
  size_t psram_size = esp_spiram_get_size() / (1024 * 1024);

  if (flash_size == 16) {
    ESP_LOGI(TAG, "Found 16MB flash size");
  } else {
    ESP_LOGE(TAG, "Flash size needs to be configured to 16MB. Found %dMB", flash_size);
  }
  if (psram_size == 8) {
    ESP_LOGI(TAG, "Found 8MB of PSRAM");
  } else {
    ESP_LOGE(TAG, "Need 8MB of PSRAM. Found %dMB", psram_size);
  }

  const esp_partition_t* running = esp_ota_get_running_partition();
  esp_ota_img_states_t ota_state;
  if (esp_ota_get_state_partition(running, &ota_state) == ESP_OK) {
      if (ota_state == ESP_OTA_IMG_PENDING_VERIFY) {
        // Assume everything is peachy just because we made it here
        ESP_LOGI(TAG, "Marking OTA update as valid");
        esp_ota_mark_app_valid_cancel_rollback();
      }
  }
  ESP_LOGI(TAG, "Running partition: %s", running->label);
#endif
}


extern "C" {

int custom_log_vprintf(const char* fmt, va_list args) {
  time_t now;
  time(&now);
  struct tm timeinfo;
  localtime_r(&now, &timeinfo);

  char time_str[64];
  strftime(time_str, sizeof(time_str), "%Y-%m-%d %H:%M:%S", &timeinfo);

  printf("[%s] ", time_str); // prepend wall-clock time
  return vprintf(fmt, args); // print the actual log message
}




void app_main(void)
{
  esp_log_set_vprintf(custom_log_vprintf);
  ESP_LOGI(TAG, "TRS-IO branch=%s, rev=%s", GIT_BRANCH, GIT_REV);
  ESP_LOGI(TAG, "Configured for %s", CONFIG);

  // Silence "spi_master: device5 locked the bus" debug messages when
  // accessing the SD card.
  esp_log_level_set("spi_master", ESP_LOG_INFO);

  check();

  init_led();  // setup LED or SSD1306
  #ifdef CONFIG_TRS_IO_SSD1306
    draw_text("Booting: Events  ", 0, 3); 
  #endif 
  init_events();        // Create the FreeRTOS EventGroup used for inter-module signaling and to track/send ESP status bits.
  #ifdef CONFIG_TRS_IO_SSD1306 
    draw_text("Booting: TRS-IO  ", 0, 3); 
  #endif 
  init_trs_io();        // Initialize the TrsIO subsystem: call TrsIO::init() to initialize registered modules and reset I/O state.
  #ifdef CONFIG_TRS_IO_SSD1306 
    draw_text("Booting: Button  ", 0, 3); 
  #endif 
  init_button();        // Configure the status (and reset on PP) GPIO pins and install ISR handlers to detect short/long button presses.
  #ifdef CONFIG_TRS_IO_SSD1306 
    draw_text("Booting: Settings", 0, 3); 
  #endif
  init_settings();      // Initialize NVS (non-volatile storage), open the settings namespace and initialize stored settings (tz, WiFi/SMB creds, ROM, screen/printer/keyboard and update flags).
  #ifdef CONFIG_TRS_IO_SSD1306 
    draw_text("Booting: SPI     ", 0, 3); 
  #endif 
  init_spi();           // Initialize the SPI bus, create a mutex for SPI transactions and register the FPGA/Cmod SPI device with its configuration.
  #ifdef CONFIG_TRS_IO_SSD1306 
    draw_text("Booting: TRS FS  ", 0, 3); 
  #endif 
  init_trs_fs_posix();  // Create/attach the POSIX-backed TRS file system (SD card), set it as the active TRS FS, and return any error string.
  #ifdef CONFIG_TRS_IO_SSD1306 
    draw_text("Booting: SPIFFS  ", 0, 3); 
  #endif 
  init_spiffs();        // Mount the SPIFFS partitions used for web/html (and other PP partitions), register a custom stat() adapter and initialize ROMs if configured.
  #ifdef CONFIG_TRS_IO_PP
    init_keyb();
  #endif
  #ifdef CONFIG_TRS_IO_SSD1306 
    draw_text("Booting: FPGA    ", 0, 3); 
  #endif 
  init_fpga();          // Wait for and verify the FPGA, upload/refresh FPGA firmware if needed (PP special handling), set FPGA-related SPI settings (screen color/printer) and clear ESP status.
  #ifdef CONFIG_TRS_IO_SSD1306 
    draw_text("Booting: WiFi    ", 0, 3); 
  #endif 
  init_wifi();          // Initialize esp-netif/event loop, register WiFi/IP event handlers, configure STA or AP mode based on stored credentials, and start WiFi.
  #ifdef CONFIG_TRS_IO_SSD1306 
    draw_text("Booting: IO      ", 0, 3); 
  #endif
   init_io();            // Configure TRS/ESP GPIO lines (addr/data/select/ESP_REQ/ESP_DONE etc.), install related ISRs and start the io and action FreeRTOS tasks.
  #ifdef CONFIG_TRS_IO_SSD1306 
    draw_text("Booting: HTTP    ", 0, 3); 
  #endif 
  init_http();          // Start the Mongoose web server task (mg_task), initialize mdns/time and begin listening for HTTP requests.
  #ifdef CONFIG_TRS_IO_SSD1306 
    draw_text("                 ", 0, 3); 
  #endif                       
  vTaskDelete(NULL);
}

} // extern "C"

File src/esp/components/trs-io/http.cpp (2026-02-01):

#include <dirent.h>
#include <sys/stat.h>
#include "retrostore.h"
#include "wifi.h"
#include "spi.h"
#include "printer.h"
#include "ntp_sync.h"
#include "trs-fs.h"
#ifdef CONFIG_TRS_IO_PP
#include "fs-roms.h"
#include "fs-spiffs.h"
#endif
#include "spiffs.h"
#include "smb.h"
#include "ota.h"
#include "led.h"
#include "io.h"
#include "settings.h"
#include "event.h"
#include "ntp_sync.h"
#include "esp_wifi.h"
#include "esp_mock.h"
#include "version-ptrs.h"
#include "version.h"
#include "mdns.h"
#include "esp_event.h"
#include "esp_log.h"
#include "mongoose.h"
#include "web_debugger.h"
#include "keyb.h"
#include <string.h>
#include "cJSON.h"
#include "xfer.h"
#include "rst.h"
#include <algorithm>

#define TAG "HTTP"
#define MDNS_NAME "trs-io"
#define PRINTER_QUEUE_SIZE 100

static const char * const ROM_DIR = "/roms";
static const char * const FILES_DIR = "/";
static mg_queue prn_queue;
static int num_printer_sockets = 0;

typedef void (*settings_set_t)(const string&);
typedef string& (*settings_get_t)();

// In build/esp-idf/main/version.cpp:
extern const char* GIT_REV;
extern const char* GIT_TAG;
extern const char* GIT_BRANCH;

// Utility class to auto-delete the JSON pointer when it goes out of scope.
class AutoDeleteJson {
    cJSON *json;

public:
    AutoDeleteJson(cJSON *json): json(json) {}
    ~AutoDeleteJson() {
        cJSON_Delete(json);
    }
};

static void set_screen_color(const string& color)
{
  uint8_t new_color = stoi(color);
  settings_set_screen_color(new_color);
  spi_set_screen_color(new_color);
}

static string& get_screen_color()
{
  static string color;
  color = to_string(settings_get_screen_color());
  return color;
}

static void set_printer_en(const string& printer_en)
{
  bool enable = (printer_en == "1");
  settings_set_printer_en(enable);
  spi_set_printer_en(enable);
}

static string& get_printer_en()
{
  static string printer_en;
  printer_en = settings_get_printer_en() ? "1" : "0";
  return printer_en;
}

static void set_keyboard_layout(const string& keyboard_layout)
{
  uint8_t new_keyboard_layout = stoi(keyboard_layout);
  settings_set_keyb_layout(new_keyboard_layout);
}

static string& get_keyboard_layout()
{
  static string keyboard_layout;
  keyboard_layout = to_string(settings_get_keyb_layout());
  return keyboard_layout;
}

static string makeDosFilename(const char *filename) {
    string dosFilename(filename);
    // TODO also check length etc.
    std::replace(dosFilename.begin(), dosFilename.end(), '.', '/');
    return dosFilename;
}

#ifdef CONFIG_TRS_IO_PP
static uint8_t get_config()
{
  static uint8_t config = 0;
  static bool is_init = false;

  if (!is_init) {
    // Get DIP switch setting
    config = spi_get_config() & 0x0f;
    is_init = true;
  }
  return config;
}

static string makeRomPathname(const char *filename) {
    return string(ROM_DIR) + "/" + filename;
}

static string makeFilesPathname(const char *filename) {
    if (strcmp(FILES_DIR, "/") == 0) {
        return string(FILES_DIR) + filename;
    } else {
        return string(FILES_DIR) + "/" + filename;
    }
}

static void mongoose_handle_get_roms(char** response,
                                     const char** content_type)
{
  DIR *d;
  struct dirent *dir;
  struct stat st;

  *response = NULL;

  cJSON* roms = cJSON_CreateArray();
  d = opendir(ROM_DIR);
  if (d == NULL) {
      ESP_LOGW(TAG, "can't open dir %s (%s)", ROM_DIR, strerror(errno));
      return;
  }
  while ((dir = readdir(d)) != NULL) {
      string pathname = makeRomPathname(dir->d_name);
      int result = stat(pathname.c_str(), &st);
      if (result == -1) {
          ESP_LOGW(TAG, "can't stat %s (%s)", pathname.c_str(), strerror(errno));
          return;
      }
      cJSON* rom = cJSON_CreateObject();
      cJSON_AddStringToObject(rom, "filename", dir->d_name);
      cJSON_AddNumberToObject(rom, "size", st.st_size);
      cJSON_AddNumberToObject(rom, "createdAt", st.st_mtim.tv_sec);
      cJSON_AddItemToArray(roms, rom);
  }
  closedir(d);

  cJSON* selected = cJSON_CreateArray();
  for (string &romFilename : settings_get_roms()) {
      cJSON_AddItemToArray(selected, cJSON_CreateString(romFilename.c_str()));
  }

  cJSON* data = cJSON_CreateObject();
  AutoDeleteJson autoDeleteJson(data);
  cJSON_AddItemToObject(data, "roms", roms);
  cJSON_AddItemToObject(data, "selected", selected);

  *response = cJSON_PrintUnformatted(data);
  *content_type = "application/json";
}

static void mongoose_handle_roms(struct mg_http_message* message,
                                 char** response,
                                 const char** content_type)
{
    // Default to error.
    *response = NULL;

    if (mg_vcasecmp(&message->method, "POST") == 0) {
        cJSON *json = cJSON_Parse(message->body.ptr);
        if (json == NULL) {
            ESP_LOGW(TAG, "Can't parse ROM JSON: %.*s", message->body.len, message->body.ptr);
            return;
        }
        AutoDeleteJson autoDeleteJson(json);

        // Fetch command.
        cJSON *command = cJSON_GetObjectItemCaseSensitive(json, "command");
        if (!cJSON_IsString(command) || command->valuestring == NULL) {
            // Command is missing, ignore request.
            ESP_LOGW(TAG, "Missing ROM command");
            return;
        }

        if (strcmp(command->valuestring, "uploadRom") == 0) {
            cJSON *filename = cJSON_GetObjectItemCaseSensitive(json, "filename");
            cJSON *contents64 = cJSON_GetObjectItemCaseSensitive(json, "contents");
            if (!cJSON_IsString(filename) || filename->valuestring == NULL ||
                    !cJSON_IsString(contents64) || contents64->valuestring == NULL) {
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
